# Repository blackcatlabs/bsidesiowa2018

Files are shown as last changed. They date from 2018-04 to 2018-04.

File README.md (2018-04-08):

# B-Sides Iowa 2018 Badge

This is the repo serves as the project development page for the B-Sides Iowa badge

## Background 

* This badge serves as B-Sides Iowa's first electronic badge!
* Consequently primary design goals included low manufacturing costs and friendly user customization.  We wanted to create an electronic badge, but didn't want to risk blowing the bank for a small non-profit conference.
* Boards were manufactured with Seeed Fusion PCB
* Other cons are welcome to use this badge as a starting point for their own badges

## Badge Specs

* ATtiny85 Microcontroller, Internal Clock 
* 12x Charlieplexed LEDs
* 8K Flash
* Momentary Reset
* Programmable Header
* Powered via CR2032 coin cell

## Badge Functions:

* LED patterns
* Personalization
* GPIOs/SPI

## Third Party Tools

The following packages were used to create this badge
* Autodesk Eagle https://www.autodesk.com/products/eagle
* Arduino IDE https://www.arduino.cc/en/Main/Software
* Sparkfun AVR Programmer https://www.sparkfun.com/products/9825

You are certainly not limited to these packages.  Any AVR compiler/programmer will do, and KiCAD is also a top notch open source alternative to Eagle. 

### Prerequisites

Be sure to configure your compiler to use the ATtiny85.  Packages are available at
https://raw.githubusercontent.com/damellis/attiny/ide-1.6.x-boards-manager/package_damellis_attiny_index.json

### Uploading firmware to badge

1. Either use an AVR programmer with POGO pins or solder a 2x3 header to the board
2. Connect the AVR programmer to the header, ensuring to match the orientation for pin 1.  (If you are using a POGO adapter at the conference, just flip the board upside down such that the microcontroller is showing.  Orient the adapter such that the ribbon cable is directly above the microcontroller.
3. Upload the code!

## Authors / Contributors

* **G Rice**

## Acknowledgments

* Tip of of the hat to D. Darko for the Tri-State Pulse Width Modulator
* Thanks to the Seeed team for the great CAM service and inspection
* Special thanks to the B-Sides sponsors for making this badge a reality

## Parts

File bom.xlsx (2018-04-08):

Designator | Manufacturer Part Number | Quantity
LED1 | LG R971-KN-1 | 1
LED2 | LG R971-KN-1 | 1
LED3 | LG R971-KN-1 | 1
LED4 | LG R971-KN-1 | 1
LED5 | LG R971-KN-1 | 1
LED6 | LG R971-KN-1 | 1
LED7 | LG R971-KN-1 | 1
LED8 | LG R971-KN-1 | 1
LED9 | LG R971-KN-1 | 1
LED10 | LG R971-KN-1 | 1
LED11 | LG R971-KN-1 | 1
LED12 | LG R971-KN-1 | 1
R1 | ERJ-P6WF1500V | 1
R2 | ERJ-P6WF1500V | 1
R3 | ERJ-P6WF1500V | 1
R4 | ERJ-P6WF1500V | 1
S1 | COM-08720 | 1
U1 | ATTINY85-20SU | 1
BT1 | PRT-11892 | 1

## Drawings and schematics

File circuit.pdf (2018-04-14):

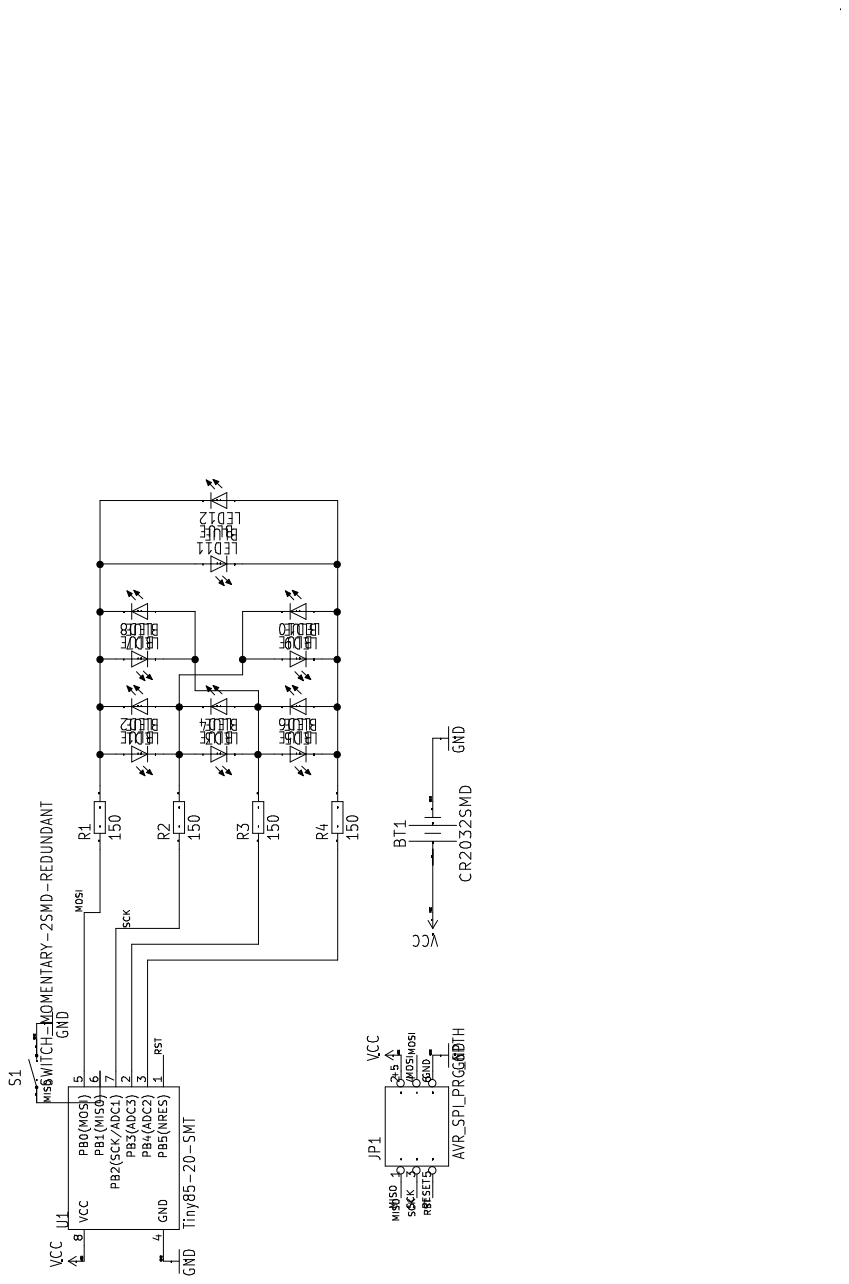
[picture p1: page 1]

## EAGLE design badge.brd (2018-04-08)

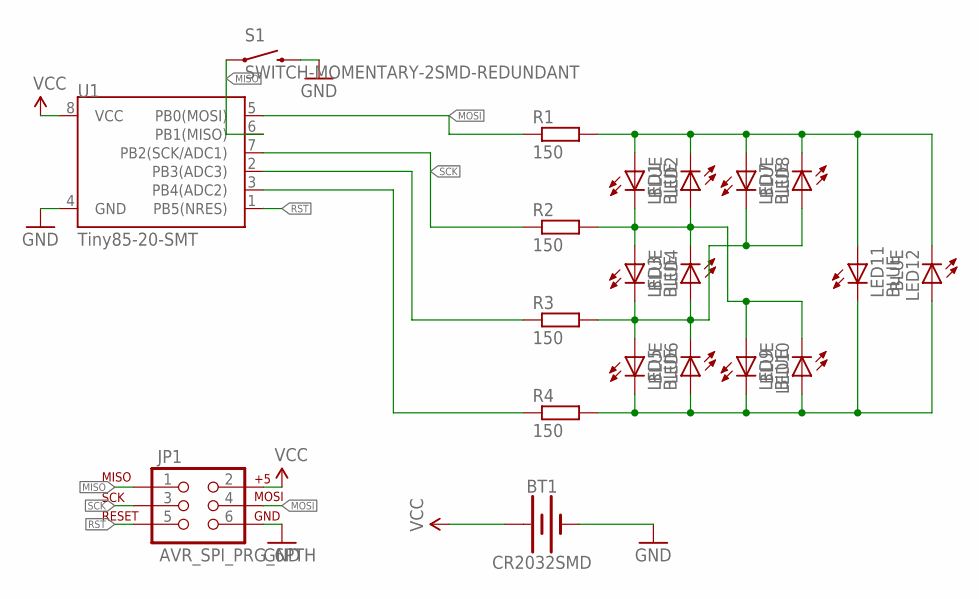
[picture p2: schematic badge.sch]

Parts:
BT1: CR2032SMD; BATTCON_20MM_4LEGS
JP1: AVR_SPI_PRG_6PTH; 2X3
LED1, LED2, LED3, LED4, LED5, LED6, LED7, LED8, LED9, LED10, LED11, LED12: BLUE; CHIP-LED0805
R1, R2, R3, R4: 150; R0805
S1: SWITCH-MOMENTARY-2SMD-REDUNDANT; TACTILE-SWITCH-SMD
U1: Tiny85-20-SMT; SO08-EIAJ

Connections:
GND: BT1.NEGATIVE (GND), JP1.6, S1.3 (2), S1.4 (2), U1.4 (GND)
MISO: JP1.1, S1.1, S1.2 (1), U1.6 (PB1(MISO))
MOSI: JP1.4, R1.1, U1.5 (PB0(MOSI))
unnamed: R4.1, U1.3 (PB4(ADC2))
unnamed: LED5.C, LED6.A, LED9.C, LED10.A, LED11.C, LED12.A, R4.2
unnamed: LED1.A, LED2.C, LED7.A, LED8.C, LED11.A, LED12.C, R1.2
unnamed: LED1.C, LED2.A, LED3.A, LED4.C, LED9.A, LED10.C, R2.2
unnamed: LED3.C, LED4.A, LED5.A, LED6.C, LED7.C, LED8.A, R3.2
PB3: R3.1, U1.2 (PB3(ADC3))
RST: JP1.5, U1.1 (PB5(NRES))
SCK: JP1.3, R2.1, U1.7 (PB2(SCK/ADC1))
VCC: BT1.POSITIVE@1 (VCC), BT1.POSITIVE@2 (VCC), BT1.POSITIVE@3 (VCC), BT1.POSITIVE@4 (VCC), JP1.2, U1.8 (VCC)

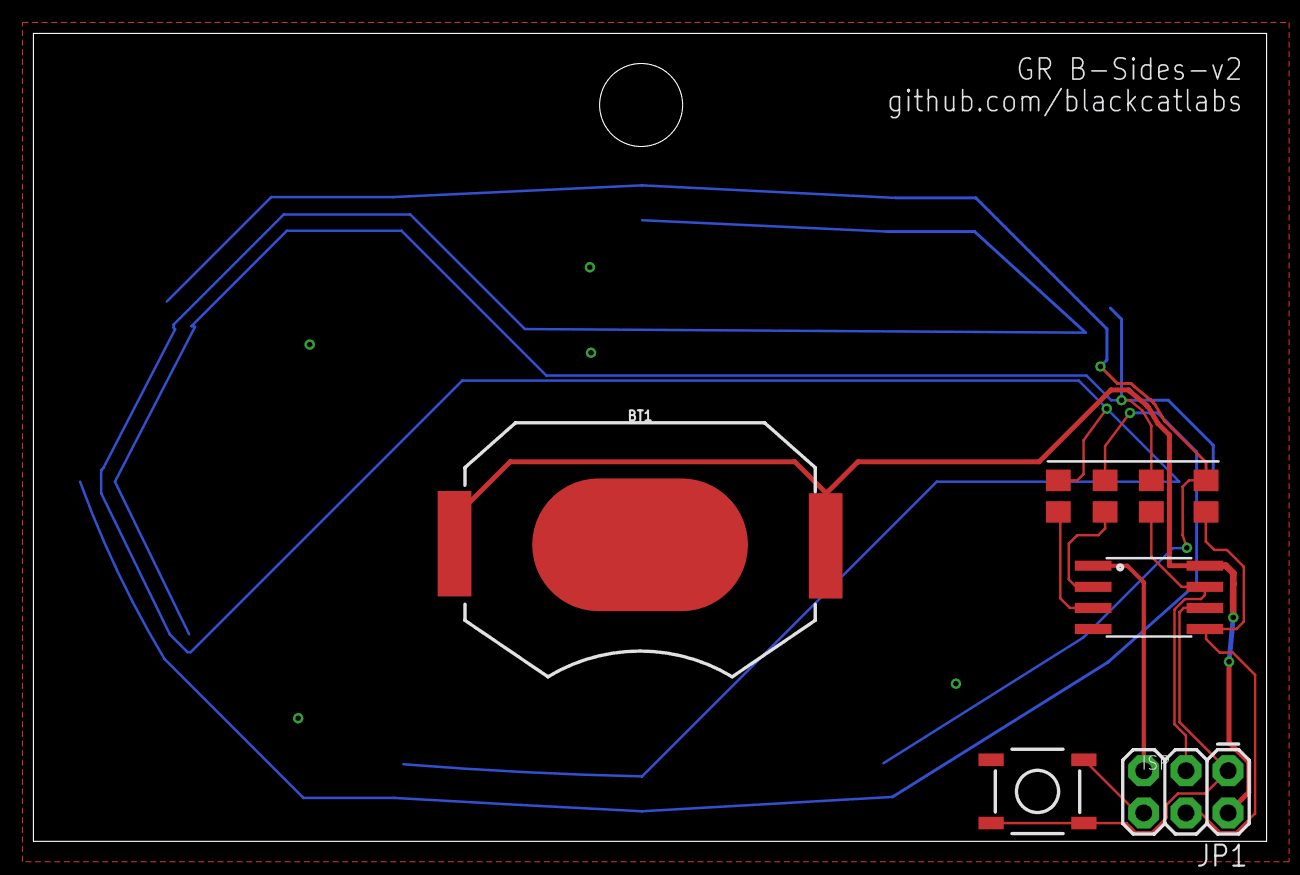
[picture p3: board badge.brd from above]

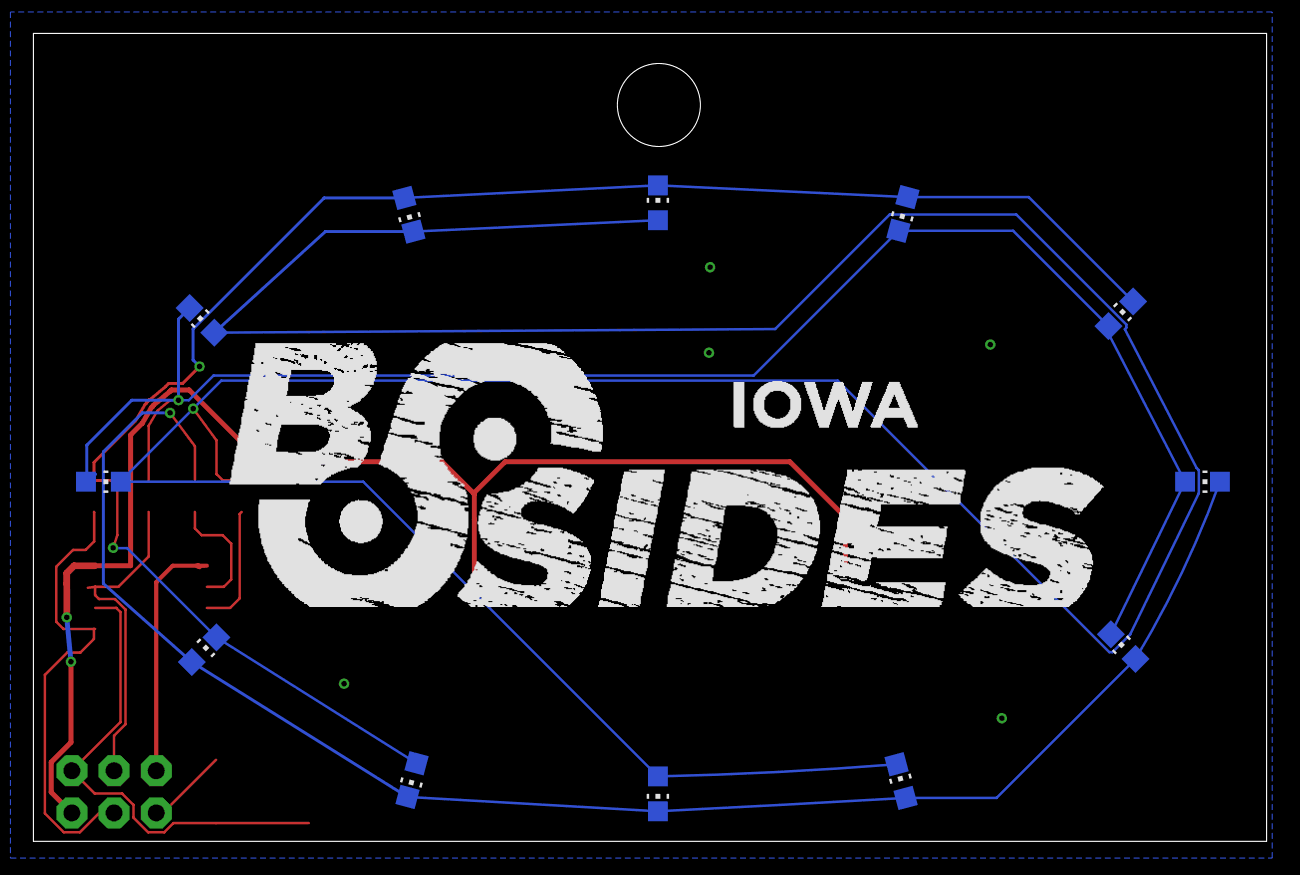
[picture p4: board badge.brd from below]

Board: 2 copper layers, 74.3 x 48.7 mm, 20 parts (12 on the bottom side), 12 nets.

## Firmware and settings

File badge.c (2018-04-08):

/* 
 * This file is part of the B-Sides Iowa 2018 badge 
 * <https://github.com/blackcatlabs/bsidesiowa2018>
 * Copyright (c) 2018 B-Sides Iowa.
 * 
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
 * You should have received a copy of the GNU General Public License 
 * along with this program. If not, see <http://www.gnu.org/licenses/>.
 */


#include <avr/sleep.h>
#include <avr/io.h>
#define nop() asm volatile("nop")

// ==================================================================================
//                ATtiny85
//              +--------+
//            --+ o  Vcc +------------
//  LED - PB3 --+        +-- PB2 - LED
//  LED - PB4 --+        +-- PB1 - RST
//  ------------+ GND    +-- PB0 - LED
//              +--------+
//
// If you are new to AVR microcontrollers, the following cheat sheet may be helpful:
//  PORTB :  Port B Data Register
//  PBn   :  Port B, Pin N
//  DDRB  :  Data direction register 
//
// For additional information, please refer to the ATtiny85 datasheet: 
// <https://www.mouser.com/ds/2/268/Atmel-2586-AVR-8-bit-Microcontroller-ATtiny25-ATti-1066528.pdf>
//
// Note: This software has been developed with novice readability in mind. Experts are 
//       encouraged to make modifications to preserve code space.  Familiarizing yourself  
//       with the PortB registers and their corresponding register bit effects can serve  
//       to conserve overall code space.    
// ==================================================================================

// Define the I/O ports to be used for the LEDs
#define LED_PIN0 PB0
#define LED_PIN1 PB2
#define LED_PIN2 PB3
#define LED_PIN3 PB4
#define RESET    PB1

boolean leds_on = true;

// Interrupt service routine
ISR(INT0_vect) {
   sleep_disable();
   leds_on = true;
}

// Setup runs once; this initializes the badge
void setup() {
   // Set the reset port pin as an input
   // All other pins will act as LED output
   digitalWrite(RESET, HIGH);
   pinMode(PB1, INPUT_PULLUP);
   
   pinMode(LED_PIN0, OUTPUT);
   pinMode(LED_PIN1, OUTPUT);
   pinMode(LED_PIN2, OUTPUT);
   pinMode(LED_PIN3, OUTPUT);

   // To conserve battery power, set to sleep mode
   sleep();
}

// This is the main routine of the program
void loop() {

   if (leds_on)
   {
      // Disable global interrupts
      cli();
      leds_on = false;
   }

   // Check for reset
   // If reset is active, do something special to sanity check
   if (!(digitalRead(RESET)))
   {
      charlieplexpin(5);
      delay(10);
      leds_off();
      delay(10);
      charlieplexpin(11);
      delay(200);
      sleep();
   }
   else
   {
      animate_leds();
   }
}

// Set the microcontroller into the sleep state 
// System wakes up when watchdog times out
void sleep()
{
   leds_off();

   // Disable the watchdog by performing the following steps:
   // Clear watchdog reset flag in the MCU status register 
   MCUSR &= ~(1 << WDRF);
   // Enable the watchdog timer
   WDTCR |= (1 << WDCE) | (1 << WDE);
   // Turn off the watchdog timer
   WDTCR = 0x00;

   // Turn off the ADC to save further power
   ADCSRA &= ~(1 << ADEN); 

   // Enable external interrupts on pin change
   GIMSK |= (1 << INT0);
   GIMSK |= (1 << PCIE);

   // Set sleep mode to conserve power
   set_sleep_mode(SLEEP_MODE_PWR_DOWN);
   sleep_enable();
   // Enable system interrupts
   sei(); 
   // System actually sleeps here
   sleep_cpu();
   
   // System continues here on interrupt
   sleep_disable();
}

void animate_leds()
{
   // Light clockwise
   for (int i = 0; i < 12; i++) {
      charlieloop(i);
   }

   // Light counterclockwise
   for (int i = 11; i >= 0; i--) {
      charlieloop(i);
   }

   // Blink top last time
   charlieloop(11);
}

// The ATtiny has relatively few I/O pins, so we drive the LEDs using a
// technique knoqn as charlieplexing.  The method uses tri-state logic
// For more info: <https://en.wikipedia.org/wiki/Charlieplexing>
void charlieloop(int pin)
{
   for (int j=0; j<4096; j++)
   {
      // This should ideally be cleaned up with better timing, but
      // it works for the moment...  Credits to darko for the PWM 
      charlieplexpin(pin);
      nop();
      nop();
      nop();
      nop();
      leds_off();
      nop();
      nop();
      nop();
      nop();
      nop();
      nop();
      nop();
      nop();
      nop();
      nop();
   }
}

void leds_off()
{
   DDRB &= ~((1 << LED_PIN0) | (1 << LED_PIN1) | (1 << LED_PIN2) | (1 << LED_PIN3));
   PORTB &= ~((1 << LED_PIN0) | (1 << LED_PIN1) | (1 << LED_PIN2) | (1 << LED_PIN3));
}

void  charlieplexpin(int id) 
{
   leds_off();

   switch (id) {
     case 0: 
      DDRB |= (1 << LED_PIN0) | (1 << LED_PIN1); 
      PORTB |= (1 << LED_PIN0);  // HIGH
      // Equivalent to digitalWrite(LED_PIN0, HIGH) 
      // We alter the registers directly for the sake of speed 
      // and a smoother animation
      PORTB &= ~(1 << LED_PIN1); // LOW
      break;
    case 1: 
      DDRB |= (1 << LED_PIN0) | (1 << LED_PIN1); 
      PORTB |= (1 << LED_PIN1);  // HIGH
      PORTB &= ~(1 << LED_PIN0); // LOW
      break;
    case 2: 
      DDRB |= (1 << LED_PIN1) | (1 << LED_PIN2); 
      PORTB |= (1 << LED_PIN1);  // HIGH
      PORTB &= ~(1 << LED_PIN2); // LOW
      break;
    case 3: 
      DDRB |= (1 << LED_PIN1) | (1 << LED_PIN2); 
      PORTB |= (1 << LED_PIN2);  // HIGH
      PORTB &= ~(1 << LED_PIN1); // LOW
      break;
    case 4: 
      DDRB |= (1 << LED_PIN2) | (1 << PB4); 
      PORTB |= (1 << LED_PIN2);  // HIGH
      PORTB &= ~(1 << PB4);      // LOW
      break;
    case 5: 
      DDRB |= (1 << LED_PIN2) | (1 << PB4); 
      PORTB |= (1 << PB4);       // HIGH
      PORTB &= ~(1 << LED_PIN2); // LOW
      break;
    case 6: 
      DDRB |= (1 << LED_PIN0) | (1 << LED_PIN2); 
      PORTB |= (1 << LED_PIN0);  // HIGH
      PORTB &= ~(1 << LED_PIN2); // LOW
      break;
    case 7: 
      DDRB |= (1 << LED_PIN0) | (1 << LED_PIN2); 
      PORTB |= (1 << LED_PIN2);  // HIGH
      PORTB &= ~(1 << LED_PIN0); // LOW
      break;
    case 8: 
      DDRB |= (1 << LED_PIN1) | (1 << LED_PIN3); 
      PORTB |= (1 << LED_PIN1);  // HIGH
      PORTB &= ~(1 << LED_PIN3); // LOW
      break;
    case 9: 
      DDRB |= (1 << LED_PIN1) | (1 << LED_PIN3); 
      PORTB |= (1 << LED_PIN3);  // HIGH
      PORTB &= ~(1 << LED_PIN1); // LOW
      break;
    case 10: 
      DDRB |= (1 << LED_PIN0) | (1 << LED_PIN3); 
      PORTB |= (1 << LED_PIN0);  // HIGH
      PORTB &= ~(1 << LED_PIN3); // LOW
      break;
    case 11: 
      DDRB |= (1 << LED_PIN0) | (1 << LED_PIN3); 
      PORTB |= (1 << LED_PIN3);  // HIGH
      PORTB &= ~(1 << LED_PIN0); // LOW
      break;
   }
}

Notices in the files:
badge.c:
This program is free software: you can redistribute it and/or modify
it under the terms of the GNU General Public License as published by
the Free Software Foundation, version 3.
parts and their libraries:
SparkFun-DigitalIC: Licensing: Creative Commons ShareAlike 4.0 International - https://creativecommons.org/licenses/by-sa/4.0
